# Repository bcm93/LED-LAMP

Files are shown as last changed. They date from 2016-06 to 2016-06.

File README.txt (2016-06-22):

AUTORES
	Belén Cebrián
	Sonia Escorza

Proyecto realizado por estudiantes de Grado en Ingeniería de Tecnologías y Servicios
de Telecomunicación en la Universidad de Zaragoza, España.

Junio 2016
----------------------------------------------------------------------------------------------------------------------------------------------------------------

Documentación

Este proyecto trata de una pelota luminosa con distintos modos de juego controlados a
partir de una App para Android. 

Para el diseño de la PCB todos los ficheros necesarios se encuentran en la carpeta ball lamp.

Para la alimentación se utilizan 3 pilas AA pero se podría ampliar este proyecto incluyendo una 
bateria, una red de carga y unos módulos de carga inductiva.Para ello, se necesitaría una base 
para el módulo transmisor con una red de adaptación para la corriente. El módulo receptor 
se encontraría dentro de la pelota junto con la batería y el circuito de carga.

El archivo BallLampApp.apk es la app Android que controla la bola, está lista para ser instalada.
IMPORTANTE: necesario emparejamiento previo al juego del Bluetooth con el dispositivo que 
	        se vaya a utilizar.
	        En cada modo de juego es necesario conectar el bluetooth, para ello se debe 
	        pulsar en el titulo de dicha pantalla. AL SALIR DE LA PANTALLA EL BLUETOOTH
	        SE DESCONECTA.

----------------------------------------------------------------------------------------------------------------------------------------------------------------

Modos de juego

Lámpara: luz en varios colores

Mascotas: cambios de luz controlados al pulsar los botones

Patata Caliente: cambios de luz a partir de los giros de la pelota. Cuando falta poco para que 
		finalice el juego la pelota empieza a parpadear. Al llegar al tiempo límite
		la pelota se pone roja.

_________________________________________________________________________________________________________

Videos de demostración

Modo Lámpara + Modo Mascotas:

https://www.youtube.com/watch?v=WMpuN2jqb0E

Modo “Patata Caliente”:

https://www.youtube.com/watch?v=RWo7kmP5fRg

-------------------------------------------------------------------------------------------------------------------------------------------------------------

AUTHORS
	Belén Cebrián
	Sonia Escorza

This project has been designed and performed by students of the Degree in Technology and
Telecommunication Services Engineering at the University of Zaragoza, Spain.

June, 2016
----------------------------------------------------------------------------------------------------------------------------------------------------------------

DOCUMENTATION

This project consists of a bright ball with different game modes which can be controlled from
an Android App.

All the necessary files for the design of the PCB are located in the directory "ball lamp".

Three AA batteries are used as energy supply, but the project could be extended to include a
rechargeable battery, a charging network, and inductive charging modules. 
For this, a base for the transmitter module would be needed together with an adapting 
network for the current. The receiver module would be located inside the ball along with the
battery and the charging circuit.

The file named "BallLampApp.apk" is the Android App which controls the ball and it is ready 
to be installed.

IMPORTANT NOTE: It is necessary to previously sincronize the ball with the Bluetooth device 
		which will be used.
		For each game mode, it is necessary to reconnect the bluetooth by clicking 
		on the title of the screen. WHEN YOU LEAVE THE SCREEN, THE BLUETOOTH 
		CONNEXION AUTOMATICALLY DISCONNECTS.

----------------------------------------------------------------------------------------------------------------------------------------------------------------

GAME MODES

"Lámpara" (Lamp): light available in several colors

"Mascotas" (Pets): light changes can be controlled by pressing the buttons

"Patata Caliente": the light changes when the ball rotates. When the game is about to end, 
		the ball starts flashing and it becomes red when the time limit is reached.

----------------------------------------------------------------------------------------------------------------------------------------------------------------

Demostration video

Lamp + Pets:

https://www.youtube.com/watch?v=WMpuN2jqb0E

Patata Caliente:

https://www.youtube.com/watch?v=RWo7kmP5fRg

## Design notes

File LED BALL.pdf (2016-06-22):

# LED BALL

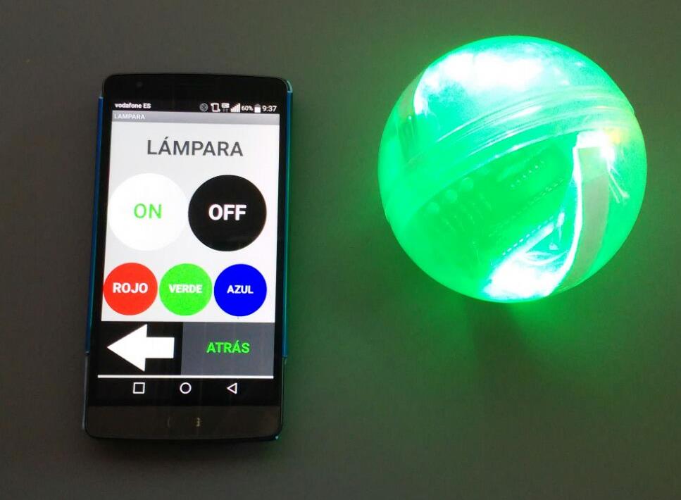
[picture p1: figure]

Belén Cebrián

Sonia Escorza

# Indice

- Diseño electrónico
- Especificaciones funcionales
- Diagrama de bloques
- Diseño de cada uno de los bloques
- Esquemático
- PCB
- Consumo
- Diseño de firmware
- Diagrama Modo Lámpara
- Diagrama Modo Mascotas
- Diagrama Modo “Patata Caliente”
- Aplicación móvil
- Video

# Diseño electrónico

Hardware

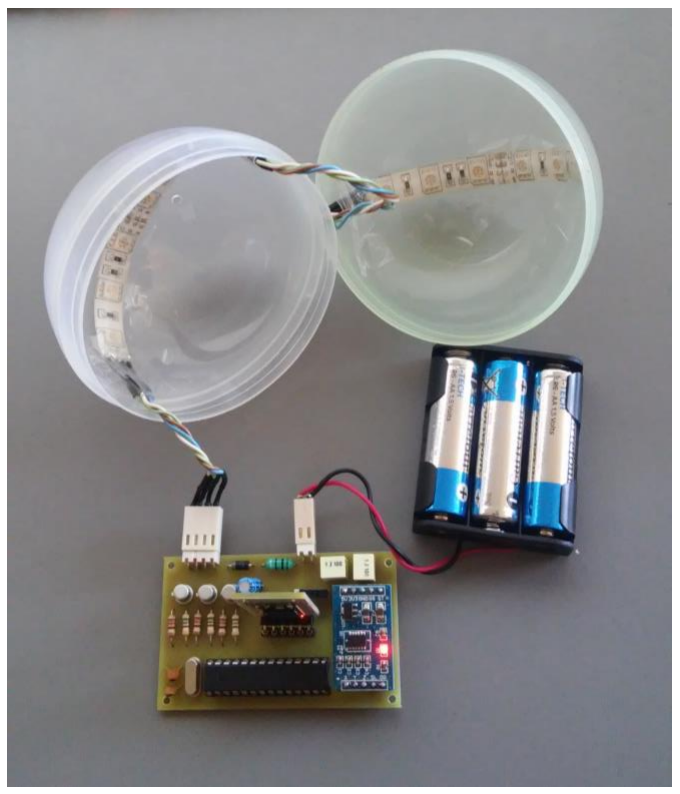
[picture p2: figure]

# Especificaciones funcionales

- Dispositivo portátil.
- Carga mediante inducción.
- Funcionamiento mediante batería (actualmente pilas)
- Iluminación LED.
- Control del modo de uso mediante aplicación móvil.
- Forma esférica para facilitar su lanzamiento.
- Precio objetivo 25 euros para 1000 unidades.

# Diagrama de bloques

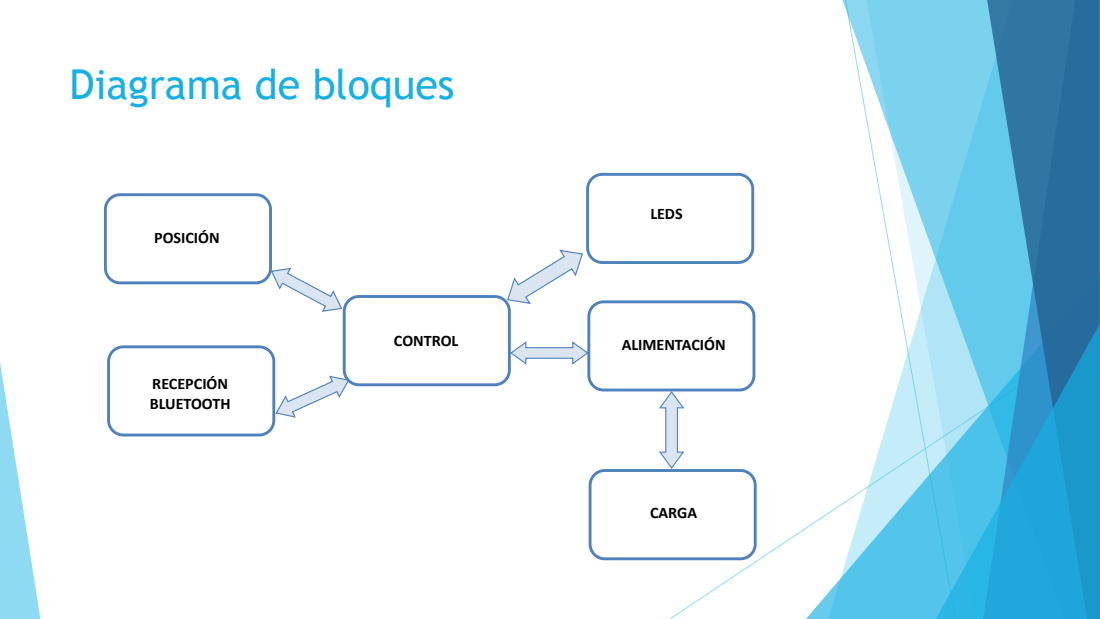
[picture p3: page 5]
RECEPCIÓN BLUETOOTH; CONTROL; CARGA; ALIMENTACIÓN; POSICIÓN; LEDS

# Diseño de cada uno de los bloques

## CONTROL:

- ATMEGA328P-PU → Distribución de tareas.
- I/O

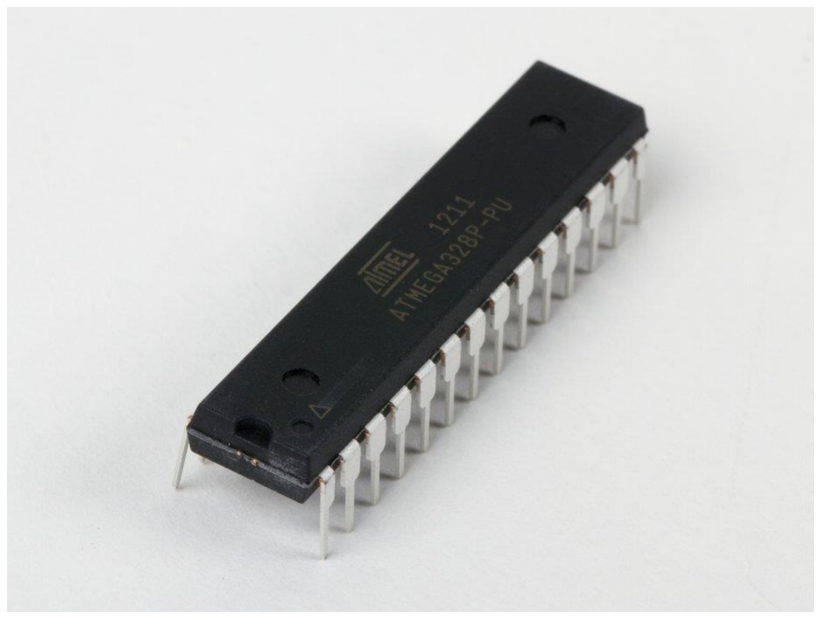
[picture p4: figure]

- Bluetooth
- Acelerómetro
- LED RGB
- Alimentación: 5V (4,68V)
- Consumo: 12mA

# Diseño de cada uno de los bloques

## RECEPCIÓN BLUETOOTH:

- Módulo bluetooth → BTH07/HC06

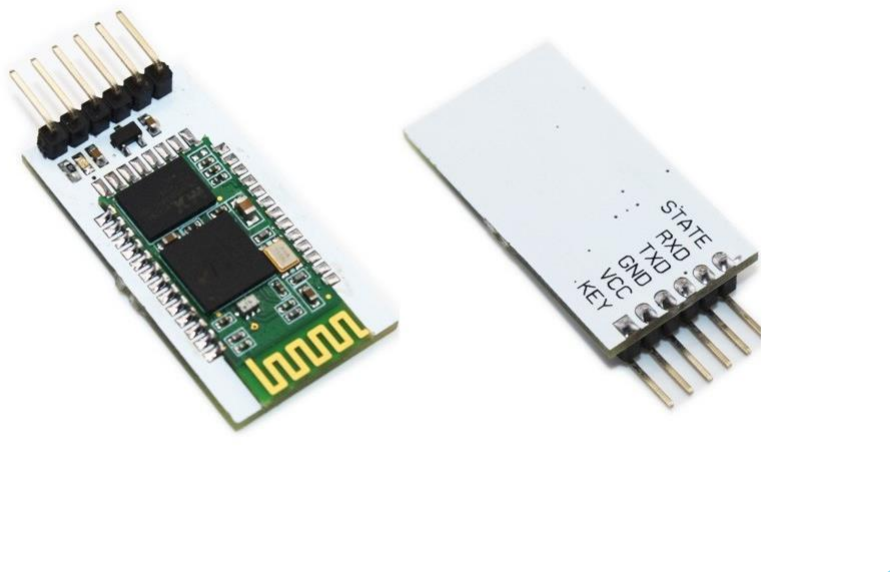
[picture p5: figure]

- Modificación de huella
- Puerta de enlace App → control
- Alimentación: 5V (4,68V)
- Consumo: 8mA

# Diseño de cada uno de los bloques

## POSICIÓN:

- Acelerómetro → MMA7361
- Alternativas:

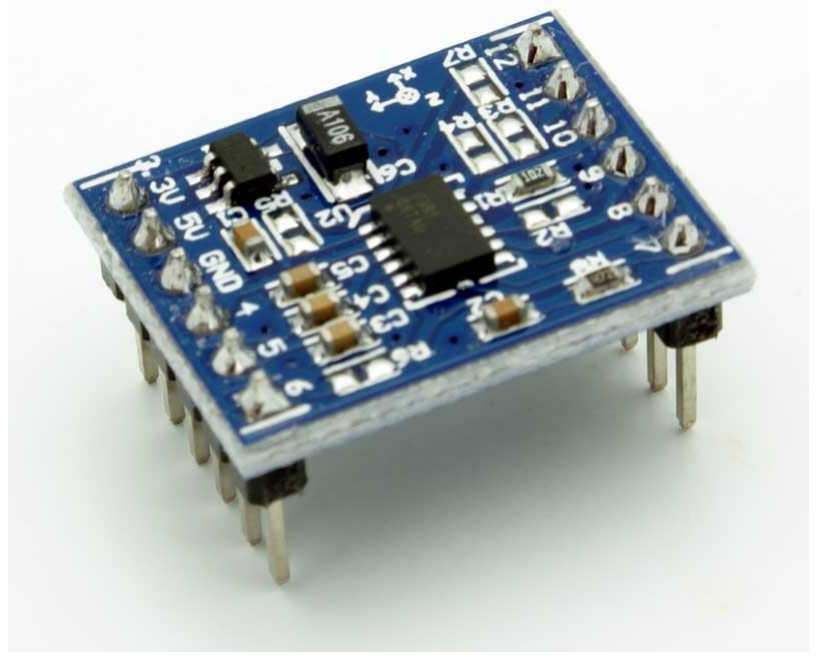
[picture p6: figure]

- Giroscopio
- Acelerómetro digital
- Modo PATATA CALIENTE.
- Modificación de huella.
- Alimentación: 5V (4,68V)
- Consumo: 0.4mA

# Diseño de cada uno de los bloques

## LEDS:

- Elementos utilizados.
- Tiras RGB

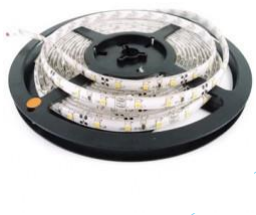
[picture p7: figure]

- Transistores BJT: 2N2222A
- Resistencias 560Ω
- Resistencias 22Ω
- Alimentación: 12V

# Diseño de cada uno de los bloques

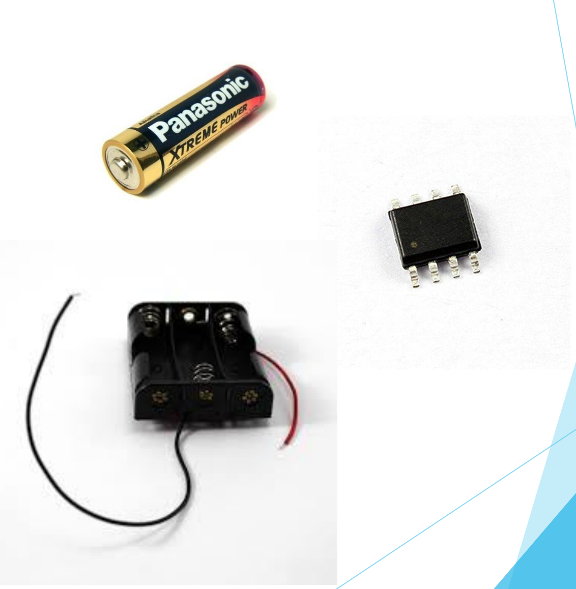
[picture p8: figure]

## ALIMENTACIÓN:

- Elementos:
- Batería → pilas AA (x3)
- Boost: 5V (4,68V) → 12V
- Consumo boost: 300mA

# Diseño de cada uno de los bloques

## CARGA:

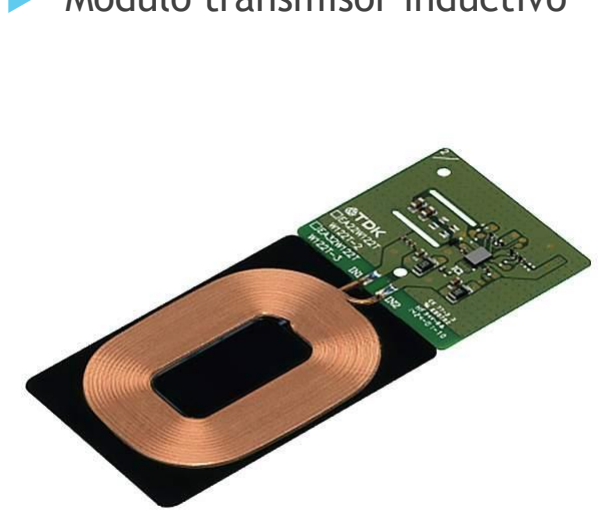
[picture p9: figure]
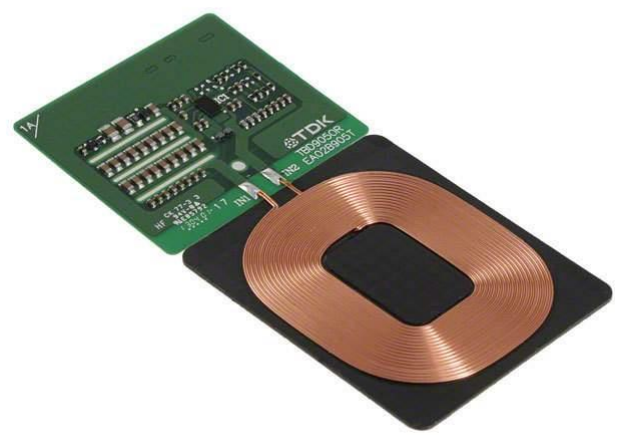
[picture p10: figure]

- Módulo transmisor inductivo | Módulo receptor inductivo

# Esquemático

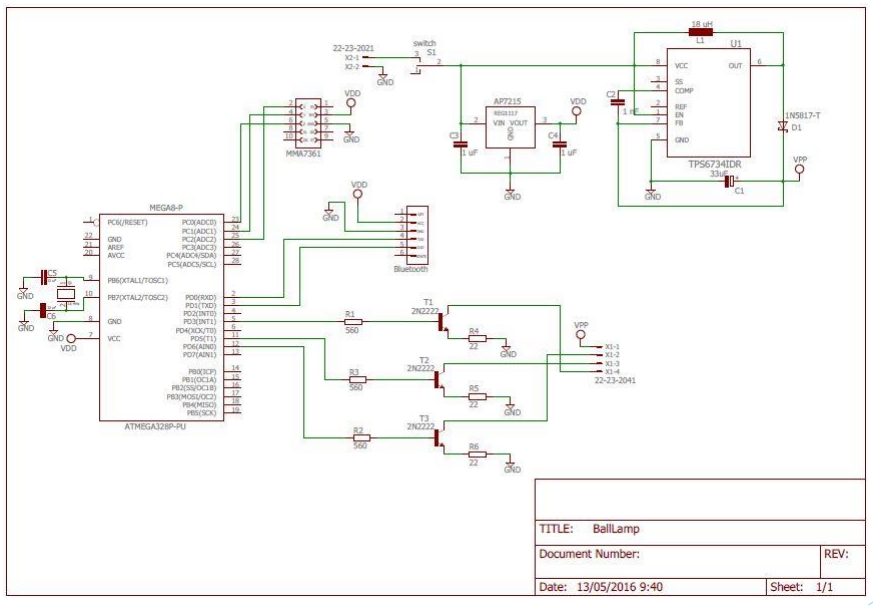
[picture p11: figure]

# Esquemático

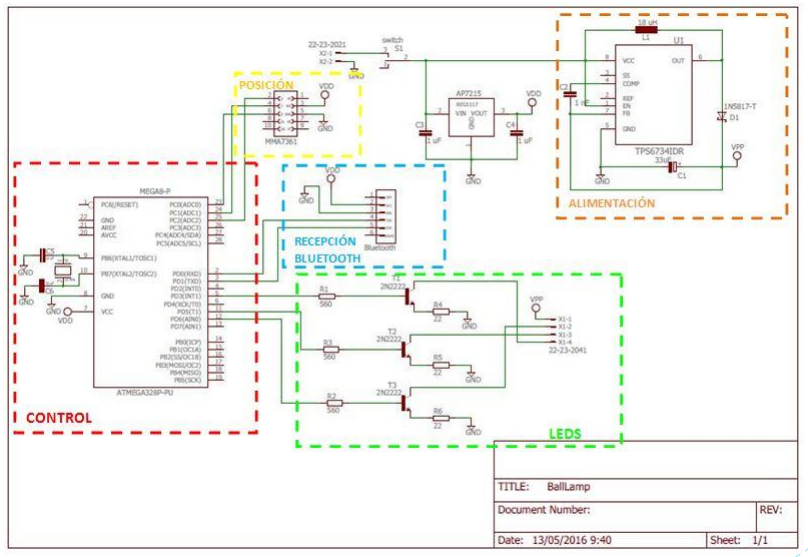
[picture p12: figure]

# PCB

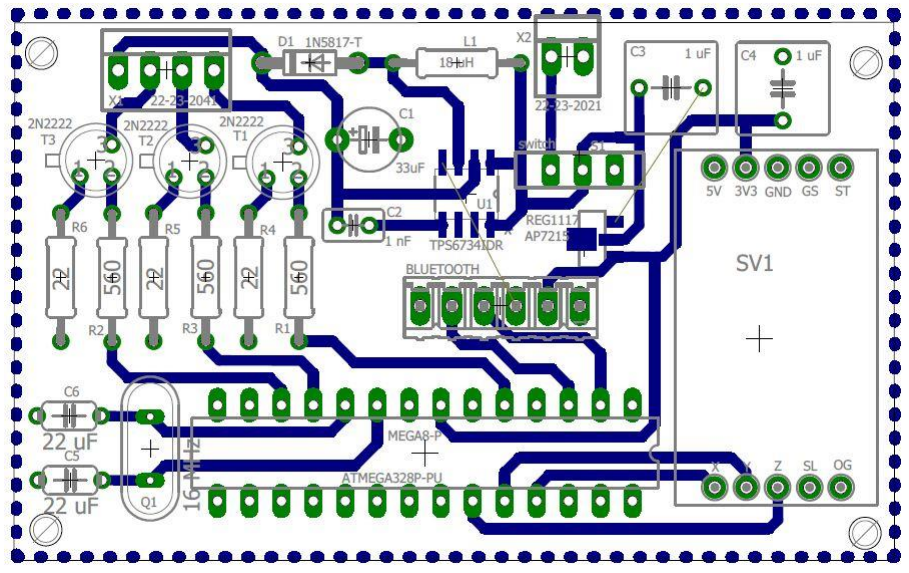
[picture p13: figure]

# PCB

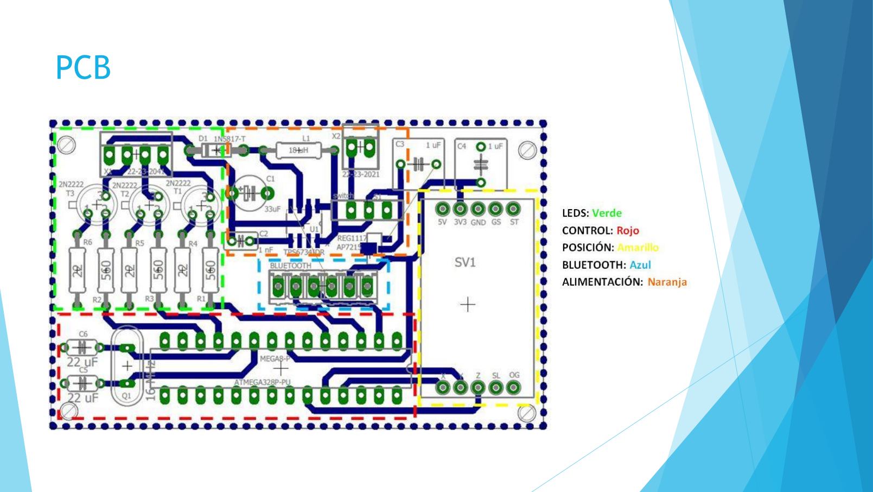
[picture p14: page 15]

# Consumo

COMPONENTE | CANTIDAD | TENSIÓN | CORRIENTE

NECESIDADES A LA ENTRADA

ATMEGA328P-PU | 1 | 4.68V(2.5 - 5V) | 12mA
MMA7361 | 1 | 4.68V(3V3 - 5V) | 0.4mA
LED RGB | 1 | 4.68V(2.7v – 11V) | 90mA
BLUETOOTH | 1 | 4.68V(3-6V) | 8mA

SALIDA BATERÍA

Pilas AA | 3 | 4.68V | 1100 - 3300mA
DURACIÓN APROXIMADA | | 30 horas

# Diseño de firmware

Firmware

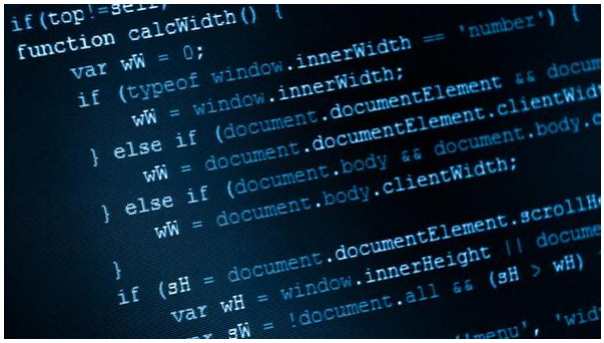
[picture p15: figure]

# Diagrama Modo Lámpara

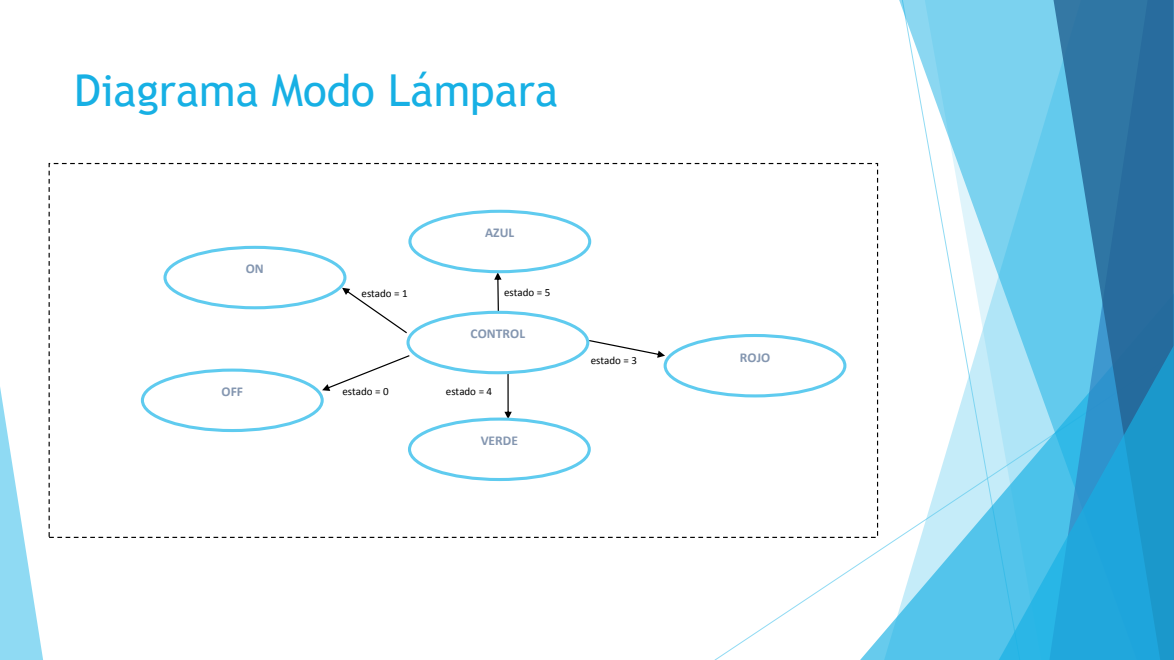
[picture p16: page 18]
estado = 4; VERDE; ROJO; OFF; AZUL; CONTROL; estado = 3; estado = 1; estado = 5; estado = 0

# Diagrama Modo Mascotas

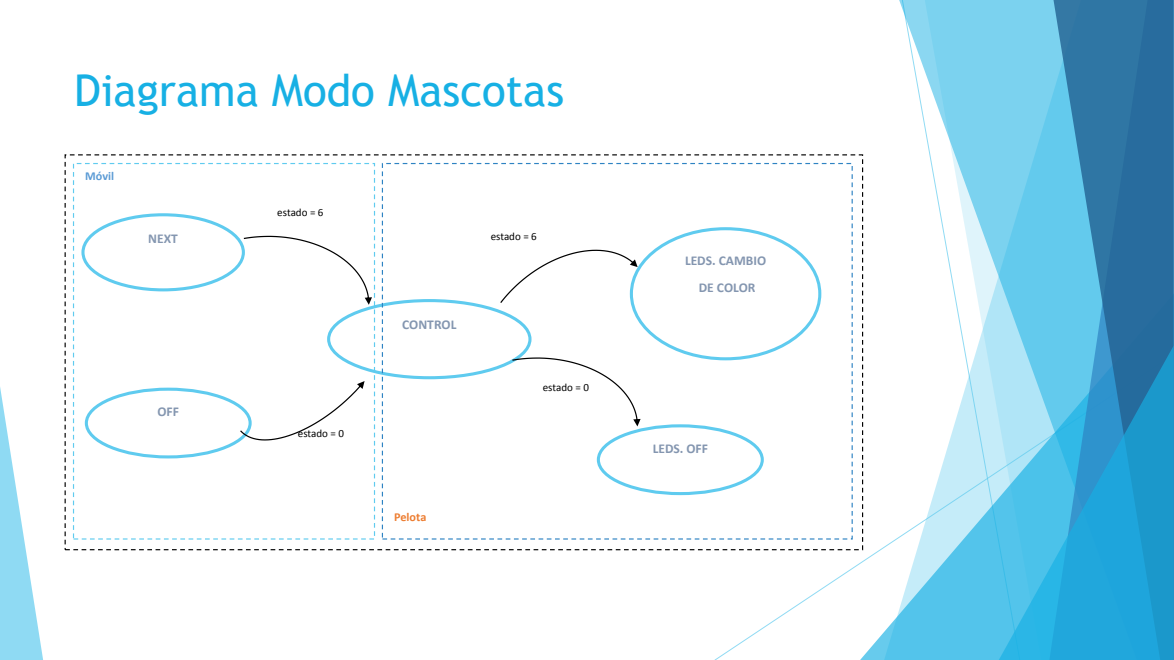
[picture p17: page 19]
CONTROL; NEXT; OFF; LEDS. CAMBIO; DE COLOR; LEDS. OFF; estado = 6; estado = 0; Móvil; Pelota

# Diagrama Modo “Patata Caliente”

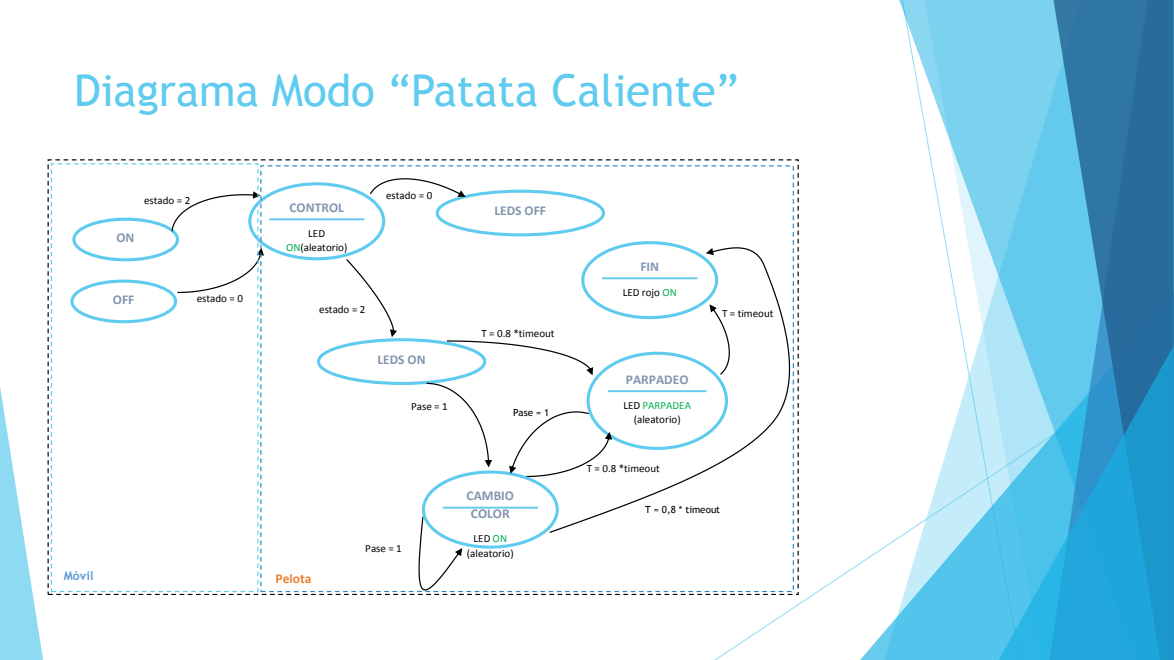
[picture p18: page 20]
T = timeout; T = 0.8 *timeout; Pase = 1; PARPADEO; LED PARPADEA (aleatorio); LEDS OFF; LEDS ON; OFF; CONTROL; LED ON(aleatorio); FIN; CAMBIO COLOR; LED ON (aleatorio); estado = 2; estado = 0; Móvil; Pelota; T = 0,8 * timeout

LED rojo ON

# Aplicación móvil

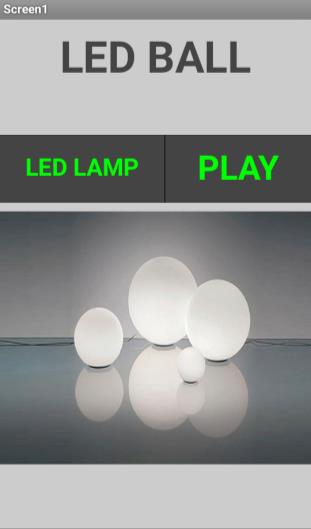
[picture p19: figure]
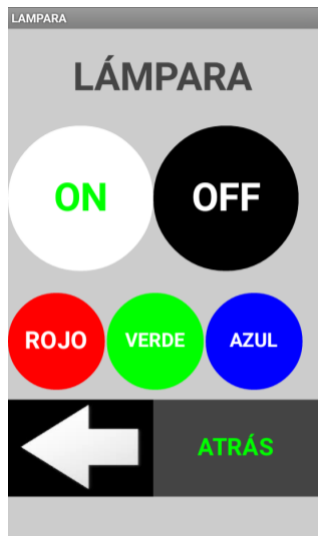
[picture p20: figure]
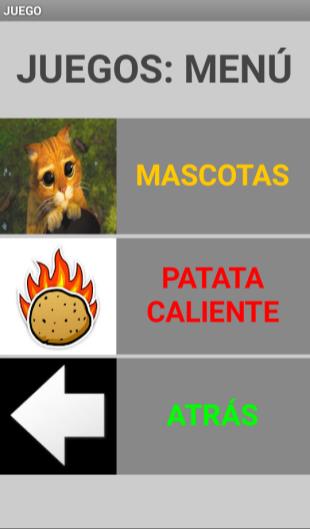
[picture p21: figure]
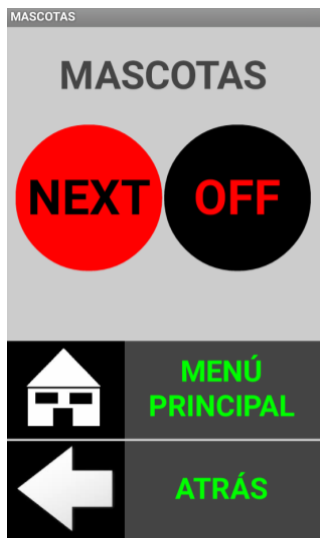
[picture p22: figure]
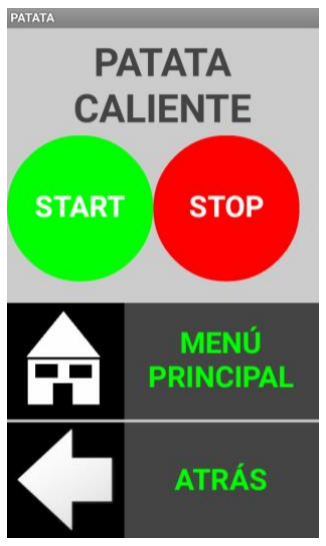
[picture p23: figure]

# Video

- Modo Lámpara + Modo Mascotas:
- https://www.youtube.com/watch?v=WMpuN2jqb0E
- Modo “Patata Caliente”:
- https://www.youtube.com/watch?v=RWo7kmP5fRg

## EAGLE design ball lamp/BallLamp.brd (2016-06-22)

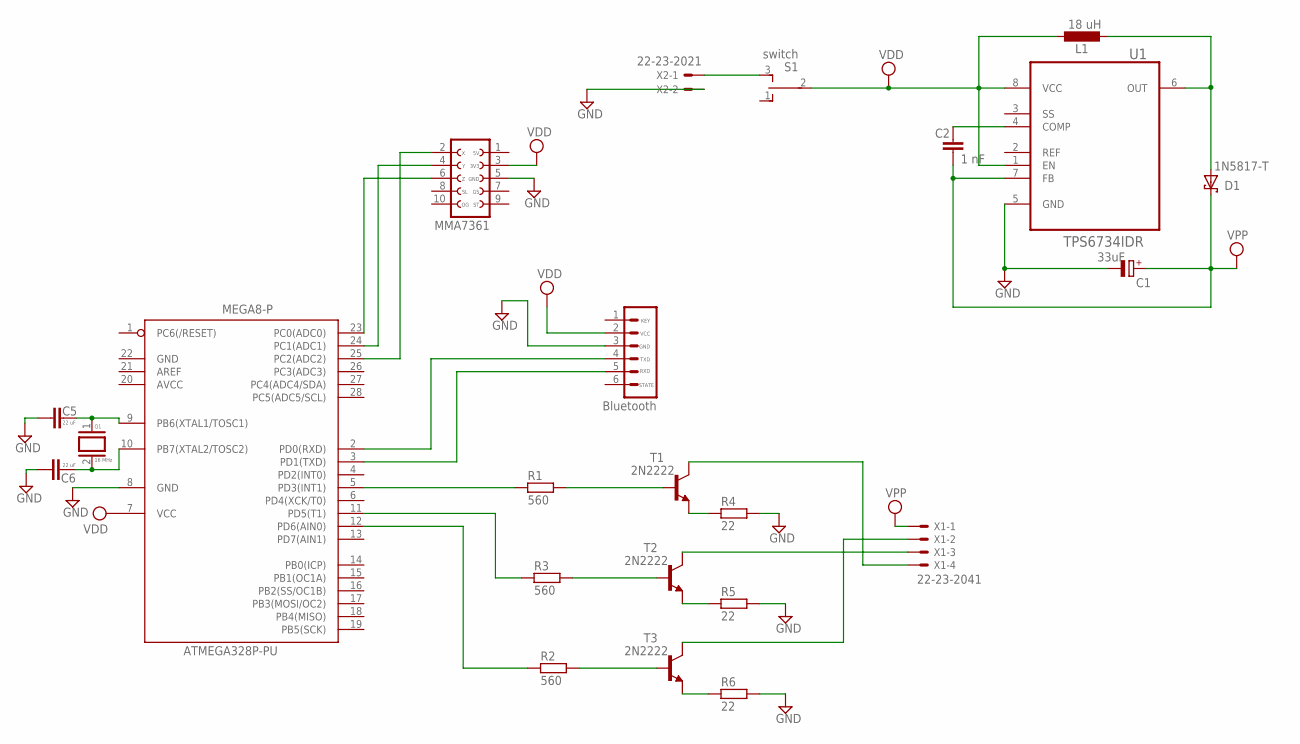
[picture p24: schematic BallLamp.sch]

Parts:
ATMEGA328P-PU: MEGA8-P; DIL28-3
BLUETOOTH: M06; 06P
C1: 33uF; E5-5
C2: 1 nF; C025-025X050
C5, C6: 22 uF; C050-024X044
D1: 1N5817-T; DO41-7.6
L1: 18 uH; 0207/10
Q1: 16 MHz; QS
R1, R2, R3: 560; 0207/10
R4, R5, R6: 22; 0207/10
S1: switch; TL3XPO
SV1: FE05-2
T1, T2, T3: 2N2222; TO18
U1: TPS6734IDR; SOIC127P600X175-8N
X1: 22-23-2041
X2: 22-23-2021

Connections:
+12V: C1.+, C2.2, D1.C, U1.7 (FB), X1.1
AVCC: ATMEGA328P-PU.20 (AVCC)
GND: ATMEGA328P-PU.8 (GND), ATMEGA328P-PU.22 (GND), BLUETOOTH.3, C1.-, C5.1, C6.1, R4.2, R5.2, R6.2, SV1.5 (GND), U1.5 (GND), X2.2
unnamed: ATMEGA328P-PU.2 (PD0(RXD)), BLUETOOTH.4
unnamed: ATMEGA328P-PU.3 (PD1(TXD)), BLUETOOTH.5
unnamed: ATMEGA328P-PU.23 (PC0(ADC0)), SV1.6 (Z)
unnamed: ATMEGA328P-PU.24 (PC1(ADC1)), SV1.4 (Y)
unnamed: ATMEGA328P-PU.25 (PC2(ADC2)), SV1.2 (X)
unnamed: ATMEGA328P-PU.5 (PD3(INT1)), R1.1
unnamed: ATMEGA328P-PU.12 (PD6(AIN0)), R2.1
unnamed: ATMEGA328P-PU.11 (PD5(T1)), R3.1
unnamed: R1.2, T1.2 (B)
unnamed: R3.2, T2.2 (B)
unnamed: R6.1, T3.1 (E)
unnamed: R2.2, T3.2 (B)
unnamed: R5.1, T2.1 (E)
unnamed: R4.1, T1.1 (E)
unnamed: T1.3 (C), X1.4
unnamed: T3.3 (C), X1.2
unnamed: T2.3 (C), X1.3
unnamed: D1.A, L1.2, U1.6 (OUT)
unnamed: S1.3 (S), X2.1
unnamed: C2.1, U1.4 (COMP)
unnamed: ATMEGA328P-PU.10 (PB7(XTAL2/TOSC2)), C6.2, Q1.2
unnamed: ATMEGA328P-PU.9 (PB6(XTAL1/TOSC1)), C5.2, Q1.1
VDD: ATMEGA328P-PU.7 (VCC), BLUETOOTH.2, L1.1, S1.2, SV1.3 (3V3), U1.1 (EN), U1.8 (VCC)

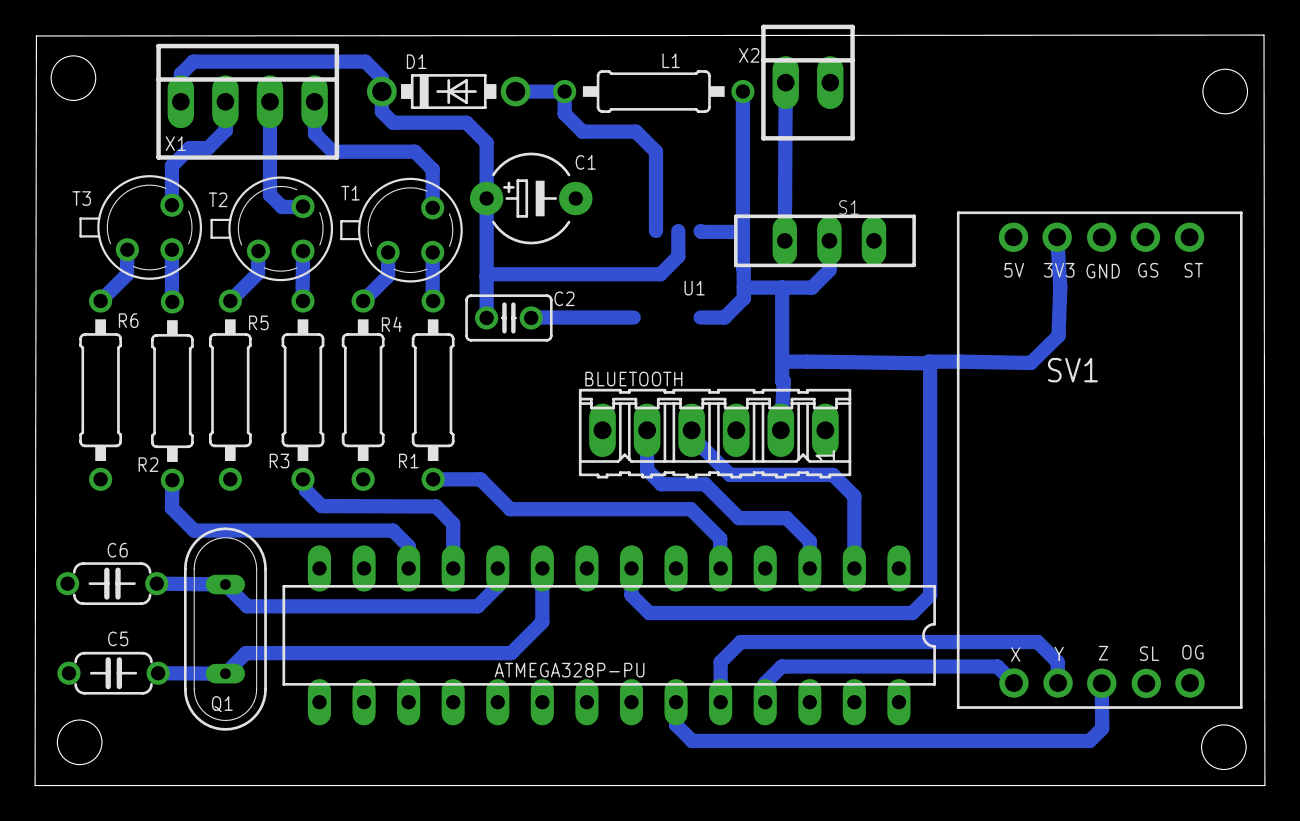
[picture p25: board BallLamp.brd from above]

Board: 2 copper layers, 70.1 x 42.8 mm, 23 parts (1 on the bottom side), 25 nets.

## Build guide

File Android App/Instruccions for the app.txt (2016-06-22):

Entrar a la siguiente dirección:

http://ai2.appinventor.mit.edu/#5984565390999552

Entrar en la sección Gallery y seleccionar BallLamp2

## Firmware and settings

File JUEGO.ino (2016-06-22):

#include <AcceleroMMA7361.h>

AcceleroMMA7361 accelero;
static int x = 0;
static int xAnterior = 0;
static int y = 0;
static int yAnterior = 0;
static int z = 0;
static int zAnterior = 0;
int estado = 0;
int rojo = 5;
int verde = 6;
int azul = 3;
int numR;
int numV;
int numA;
static int timeout = 0;
static int contador = 0;
static int parpadeo = 0;
static float tiempoAnterior = 0;
static float tiempoActual = 0;

void setup()
{
  Serial.begin(9600);
  accelero.begin(13, 12, 11, 10, A2, A1, A0);
  accelero.setARefVoltage(5);                   //sets the AREF voltage to 3.3V
  accelero.setSensitivity(LOW);                   //sets the sensitivity to +/-6G
  accelero.calibrate();
}

void loop()
{
  xAnterior = x;
  yAnterior = y;
  zAnterior = z;
  x = accelero.getXAccel();
  y = accelero.getYAccel();
  z = accelero.getZAccel();

  if(Serial.available()>0) {
    estado = Serial.read();
  }
  
  //LÁMPARA
  if(estado == '1') { //Luz blanca
    analogWrite(rojo, 255);
    analogWrite(verde, 255);
    analogWrite(azul, 255);
  }
  if( estado == '3'){ //Luz roja
    analogWrite(rojo, 255);
    analogWrite(verde, 0);
    analogWrite(azul, 0);
  }
  if( estado == '4'){ //Luz verde
    analogWrite(rojo, 0);
    analogWrite(verde, 255);
    analogWrite(azul, 0);
  }
  if( estado == '5'){  //Luz azul
    analogWrite(rojo, 0);
    analogWrite(verde, 0);
    analogWrite(azul, 255);
  }

  //PATATA CALIENTE
  if(estado == '2') { 
    
    //Control del TIMEOUT
    if(timeout == 0){
      timeout = random(100, 150);
      parpadeo = timeout / 8;
    }
    else {
      contador ++;
    }
        
    if (contador > (timeout - parpadeo)){ //Parpadeo
      if(contador == timeout){ //Fin del TIMEOUT
        timeout = 0;
        contador = 0;
        estado = 15;
        parpadeo = 0;
        analogWrite(rojo, 255);
        analogWrite(verde, 0);
        analogWrite(azul, 0);
      }

      else{
        if( (x > xAnterior + 150) || (x < xAnterior - 150) ||(y > yAnterior + 150) || (y < yAnterior - 150) ||(z > zAnterior + 150)){ //Lanzamiento
          tiempoActual = millis();
          if(tiempoActual > (tiempoAnterior + 500)) {
            numR = random(0, 256);
            numV = random(0, 256);
            numA = random(0, 256);
            analogWrite(rojo, numR);
            analogWrite(verde, numV);
            analogWrite(azul, numA);

            tiempoAnterior = tiempoActual;
          }
          else {
            analogWrite(rojo, 0);
            analogWrite(verde, 0);
            analogWrite(azul, 0);
            delay(1000);
            analogWrite(rojo, numR);
            analogWrite(verde, numV);
            analogWrite(azul, numA);
          }
        }
      
        else{ //Estático
          analogWrite(rojo, 0);
          analogWrite(verde, 0);
          analogWrite(azul, 0);
          delay(1000);
          analogWrite(rojo, numR);
          analogWrite(verde, numV);
          analogWrite(azul, numA);
        }

      }
    }
    else { 
      if( (x > xAnterior + 150) || (x < xAnterior - 150) ||(y > yAnterior + 150) || (y < yAnterior - 150) ||(z > zAnterior + 150)){ //Lanzamiento
        tiempoActual = millis();
        if(tiempoActual > (tiempoAnterior + 500)) {
          numR = random(0, 256);
          numV = random(0, 256);
          numA = random(0, 256);
          analogWrite(rojo, numR);
          analogWrite(verde, numV);
          analogWrite(azul, numA);

          
          tiempoAnterior = tiempoActual;
        }
      }
      
      else{ //Estático
        analogWrite(rojo, numR);
        analogWrite(verde, numV);
        analogWrite(azul, numA);
      }
    }
  }

  // MASCOTAS
  if(estado == '6') { 
    numR = random(0, 256);
    numV = random(0, 256);
    numA = random(0, 256);
    analogWrite(rojo, numR);
    analogWrite(verde, numV);
    analogWrite(azul, numA);
    estado = 15;
  }
  if(estado == '0') { //Luz Apagada
    analogWrite(rojo, 0);
    analogWrite(verde, 0);
    analogWrite(azul, 0);
    timeout = 0;
    contador = 0;
    parpadeo = 0;
  }
  delay(500);                                     
}
